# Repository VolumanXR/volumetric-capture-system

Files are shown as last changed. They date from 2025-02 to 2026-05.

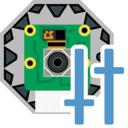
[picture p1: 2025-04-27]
src/res/master_camera_controller.png

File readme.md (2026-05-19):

**EN** | [DE](/README.de.md)

<p align="center">
  Volumetric Capture System Logo
</p>

# VolumanXR – Volumetric Capture System

This module is part of the **VolumanXR** project and implements a complete **synchronized volumetric video capture system** using Raspberry Pis and the Raspberry Pi Camera Module V3. The system enables real-time, multi-camera video acquisition for 4D Gaussian Splatting.
<p align="center">
  Animated results of a scan
</p>

It includes:
- A scalable and customizable camera rig
- A decentralized control system with synchronized recording
- GUI tools for capture, calibration, and download
- Automation scripts and config management

> **Maintenance Notice**\
>This repository primarily serves as a documentation and reference space for the Volumetric Capture System of the VolumanXR research project. Further development occurs on an occasional basis and is not continuous. Repositories may receive updates from time to time, but regular maintenance and long-term support should not be assumed.

---

## 📦 Repository Structure
```text
volumetric-capture-system/
├── readme.md
├── requirements.txt
├── cad/                           # 3D-printable camera holder models
├── src/
│   ├── master_camera_controller.py
│   ├── master_capture_controller.py
│   ├── master_download_manager.py
│   ├── config/                    # Device settings and camera parameters
│   ├── lib/                       # Shared configuration and SSH utilities
│   ├── remote/                    # Scripts executed on Raspberry Pis
│   ├── res/                       # Icons and sound files used by GUI tools
│   └── utils/                     # Utility scripts for setup and control
```

---

## 🔧 Hardware Context
<p align="center">
  Volumetric Capture System Overview Image
</p>

- **Camera Rig**: Custom-built frame using aluminum extrusion profiles (not included in repo).
- **Cameras**: Raspberry Pi 4B (1GB) + Camera Module V3
- **Devices**: approx. 70 Raspberry Pi units
- **Mounts**: 3D-printable camera holders (provided in `cad/`)
- **Trigger**: Software-synchronized using NTP + ZeroMQ

> *The structural skeleton is specific to our use case and therefore excluded to encourage custom modifications. It is based on standard 20×20mm aluminum extrusions, and the included 3D-printable camera holders are fully compatible with this profile size. A full parts list for the frame construction can be provided upon request.*

---

## 🚀 Core Functionality

### 🎚️ Master Camera Controller (`master_camera_controller.py`)
- GUI tool for live preview and global camera calibration
- Modify ISO, shutter speed, white balance, resolution
- Save unified settings to `camera_settings.json`

### 📸 Master Capture Controller (`master_capture_controller.py`)
- GUI-based tool to control still or video capture
- Synchronizes all agents to a single start time
- Frame drop detection and timestamp logging
- Uses `camera_list.json` to identify and manage all configured camera devices on the network

### 🔄 Master Download Manager (`master_download_manager.py`)
- GUI tool to download sessions from all Pis
- Organizes files, checks completeness, enables conversion
- Supports offline mode for post-capture frame extraction

---

## 🧠 Remote Agents (Running on Raspberry Pis)

Remote-side scripts are located in `src/remote/` and are triggered via SSH by the master control GUIs. Each script is responsible for a core function during capture, calibration, or data transfer.

### Main Remote Modules

- `remote_camera_controller.py`  
  Handles calibration commands from the Master Camera Controller (`master_camera_controller.py`), such as adjusting focus or setting exposure.

- `remote_capture_controller.py`  
  Receives synchronized recording instructions from the Master Capture Controller (`master_capture_controller.py`), executes the capture locally, and logs metadata.

- `remote_download_manager.py`  
  Runs a simple file server on each Pi to make captured sessions available for download, coordinated by the Master Download Manager (`master_download_manager.py`).

### Remote Utilities (`src/remote/utils/`)

- `remote_set_cam_number.py` — Sets a unique hostname, ID (e.g. `CAM00`) and fixed IP  
- `remote_test_camera_settings.py` — Applies a series of camera configurations and captures test images for validation

---

## 🧰 General Utilities

Located in `src/utils/`, these tools support discovery, setup, and remote control:

- `launcher.py`  
  CLI for development, debugging, and deployment. Supports multithreaded SSH to start/stop/update remote scripts on all Pis.

- `search_devices.py`  
  Scans the local subnet using multithreaded pings to identify active devices. Attempts to resolve hostnames for each responsive IP.

- `set_up_chrony_via_ssh.py`  
  Configures time synchronization on all Pis using Chrony for frame-accurate triggering.

- `master_set_cam_number.py`  
  Assigns camera numbers and hostnames from the master side during setup.

- `build.py`
  Preconfigured build script for all three main programs

---

## ⚙️ Configuration Files

- `camera_list.json` — List of camera hostnames, IPs, and their custom focus offsets
- `camera_settings.json` — Default global exposure settings (shutter, ISO, etc.)

Each Pi is matched via hostname (e.g. `CAM00`, `CAM01`, ...) and receives a fixed IP address in the `10.x.x.x` range.  
The **last octet of the IP corresponds to the camera number**, starting at `.100` — for example:
- `CAM00` → `10.x.x.100`
- `CAM01` → `10.x.x.101`

---
## 🗂 File Naming Convention

Captured videos and still images follow the pattern:
```
<session_name>_<ip_suffix>.<extension>
```

Examples:
- `DanceA_103.mp4` — video from device with IP `10.x.x.103`
- `PoseTest_115.jpg` — still image from device with IP `10.x.x.115`

This format ensures files can easily be traced to their originating capture device.

---

## 🎛 Dependencies

Install dependencies for local tools:

```bash
pip install -r requirements.txt
```
Recommended environment:
- Python 3.10+
- Works on Windows/macOS (for GUI tools) and Raspberry Pi OS (for remote agents)

---

## 👥 Contributions
### Code Contributors

- **Kai Altwicker** — Rig design, synchronization, master control architecture  
- **Dennis Amuser** — Remote agent design, firmware imaging, network & automation

### Publications
- **[IEEE VR26](https://doi.org/10.1109/VRW70859.2026.00274)**\
[Steffen Stein](https://www.linkedin.com/in/steffen-sascha-stein/), [Dennis Amuser](https://github.com/dooonnis), [Kai Altwicker](https://github.com/tallAldi), David Mertens, Matthias Bullert Alisa Rüge, David Martin Karf, Kristoffer Waldow, [Arnulph Fuhrmann](https://www.linkedin.com/in/arnulph-fuhrmann-291420279/)
```bibtex
@INPROCEEDINGS{11489551,
  author={Stein, Steffen-Sascha and Amuser, Dennis and Altwicker, Kai and Mertens, David and Bullert, Matthias and Ruge, Alisa and Karg, David Martin and Waldow, Kristoffer and Fuhrmann, Arnulph},
  booktitle={2026 IEEE Conference on Virtual Reality and 3D User Interfaces Abstracts and Workshops (VRW)}, 
  title={A Scalable and Cost-Effective Multi-View Capture System for Photorealistic Dynamic Human Reconstruction}, 
  year={2026},
  volume={},
  number={},
  pages={1199-1200},
  keywords={Broadcasting;Broadcast technology;Anisotropic;Filters;Graphical user interfaces;Avatars;Protocols;Videos;HTTP;Video equipment;Avatars;Capture System;Virtual Humans;Radiance Fields},
  doi={10.1109/VRW70859.2026.00274}}
```

### Acknowledgements
- Prof. Dr.-Ing. Fuhrmann
- GatewayTHK
- Makerspace TH Köln 
- Zentralwerkstatt Elektrotechnik, 

---

## 📄 License
 
Please refer to the [`LICENSE`](/LICENSE) file for full terms.

Third-party license notices are provided in [`THIRD_PARTY_NOTICES.md`](/NOTICE-THIRD-PARTY.md).

---

> ℹ️ This repository is part of the VolumanXR project. \
> For full project context, visit the [VolumanXR](https://github.com/VolumanXR) page.

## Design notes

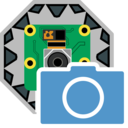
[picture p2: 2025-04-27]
src/res/master_capture_controller.png

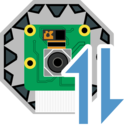
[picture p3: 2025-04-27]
src/res/master_download_manager.png

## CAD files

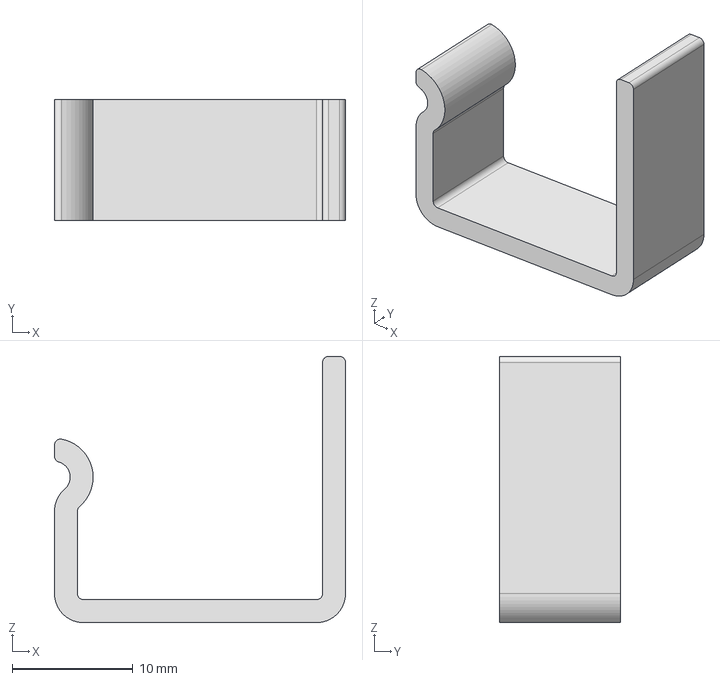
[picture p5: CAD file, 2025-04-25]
cad/Aruco_Marker_Clamp.stp
24.1 x 10.0 x 22.0 mm

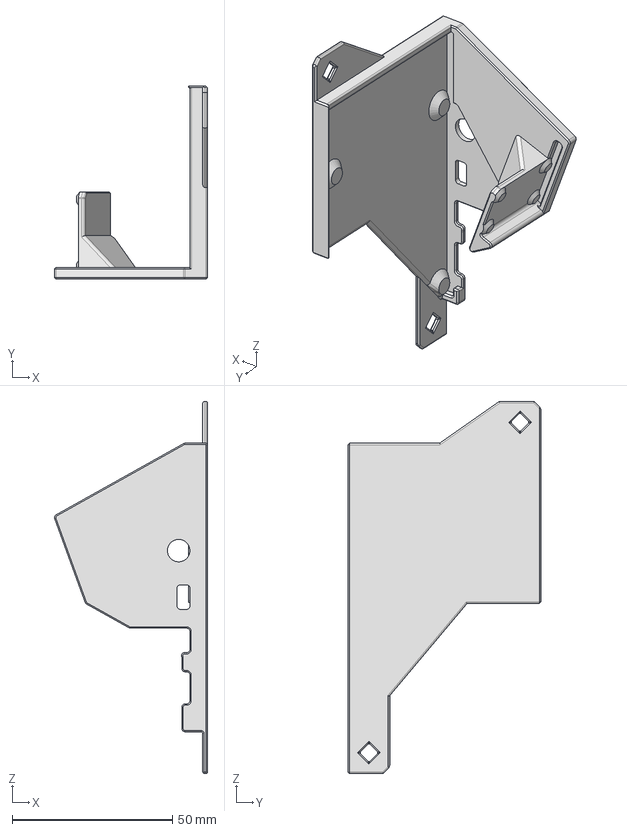
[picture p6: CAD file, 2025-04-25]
cad/Cameraholder_20deg_topDown.stp
47.7 x 60.1 x 116.0 mm

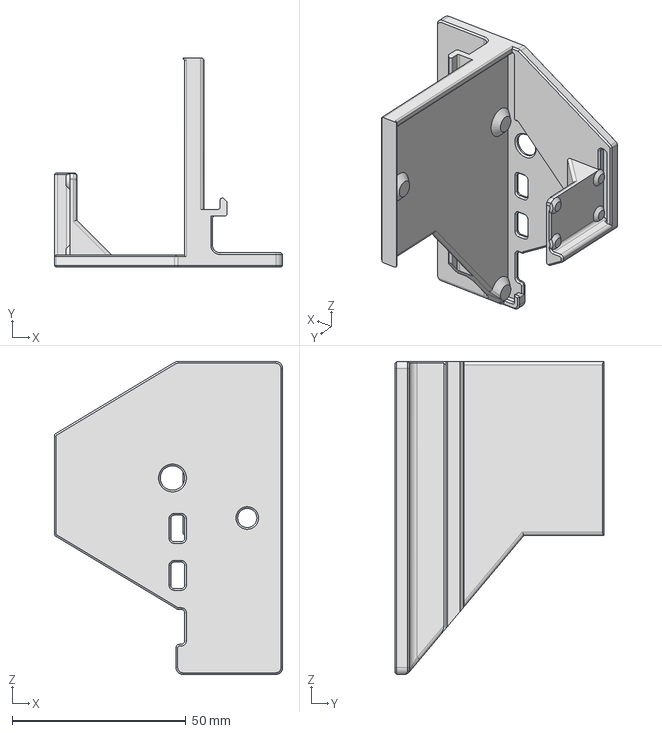
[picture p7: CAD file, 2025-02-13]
cad/Cameraholder_straight_90deg.stp
65.7 x 60.1 x 90.0 mm

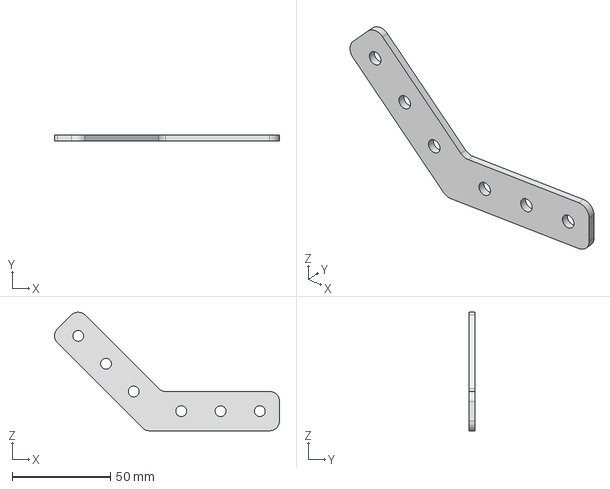
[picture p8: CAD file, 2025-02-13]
cad/Verbinder_45deg.stp
114.5 x 3.00 x 60.3 mm

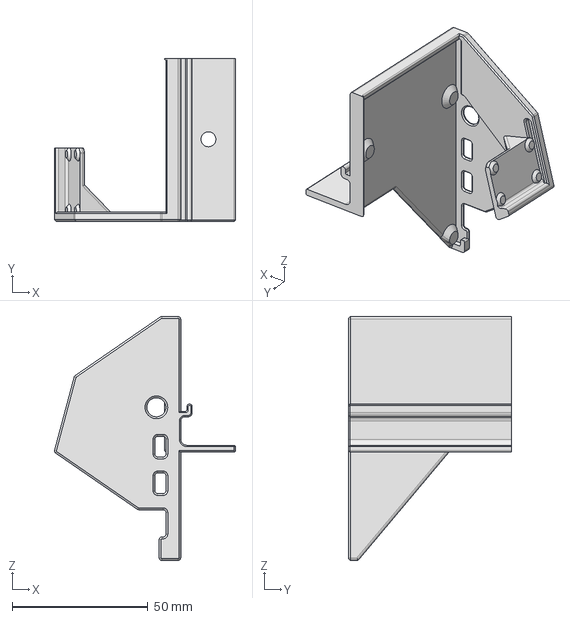
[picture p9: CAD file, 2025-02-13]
cad/Cameraholder_15deg_down.stp
66.8 x 60.1 x 90.0 mm

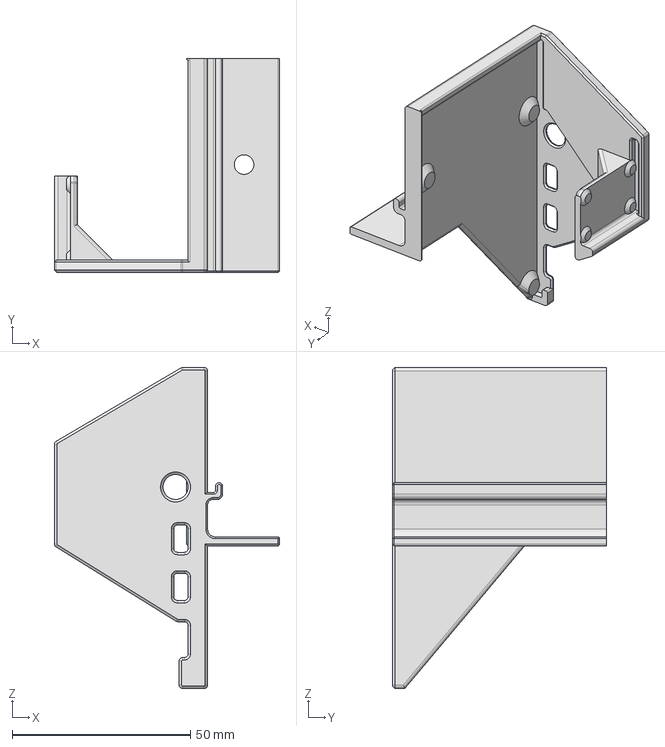
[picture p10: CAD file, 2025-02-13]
cad/Cameraholder_straight.stp
63.2 x 60.1 x 90.0 mm

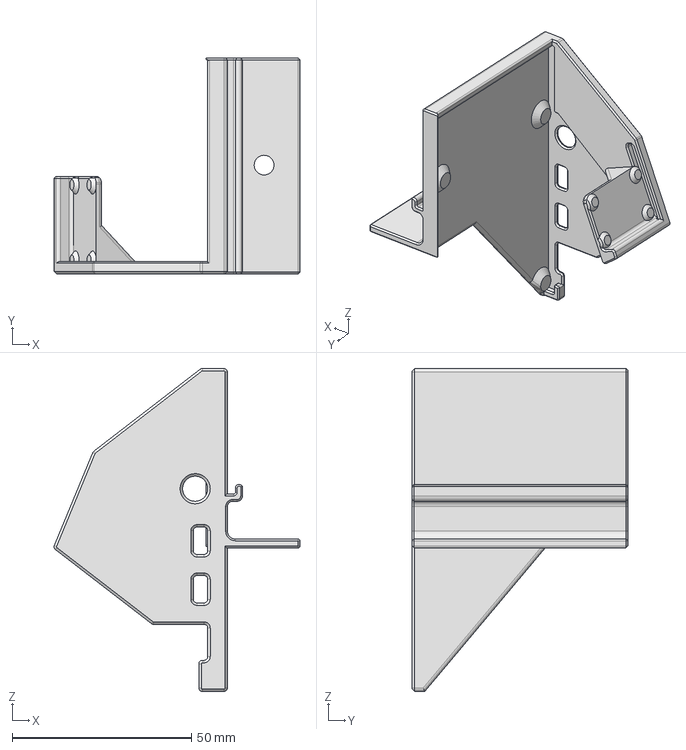
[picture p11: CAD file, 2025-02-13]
cad/Cameraholder_22_5deg_down.stp
68.5 x 60.1 x 90.0 mm

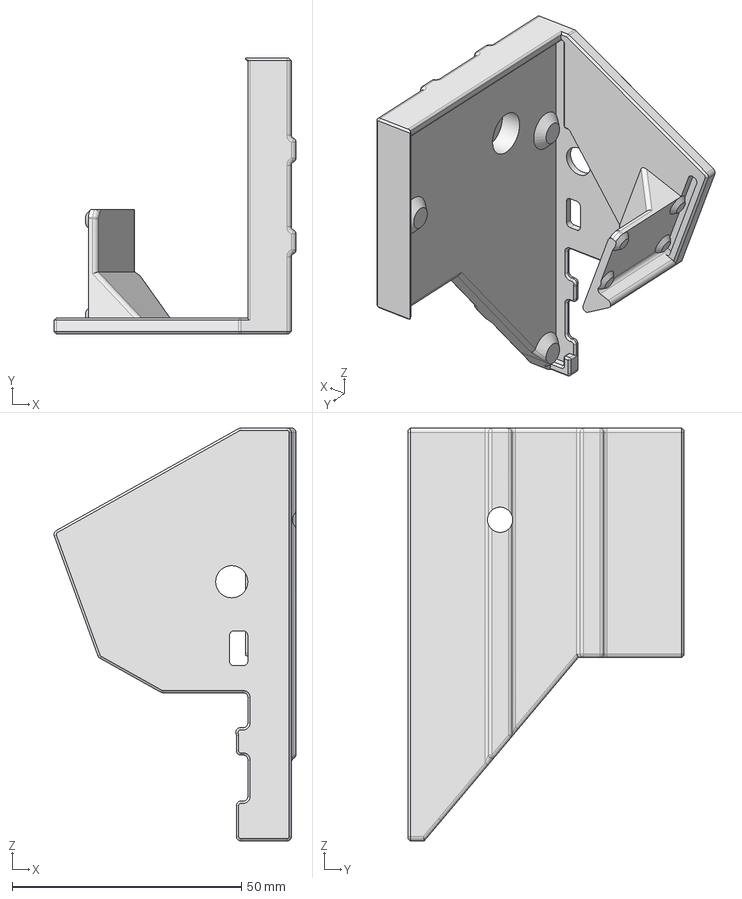
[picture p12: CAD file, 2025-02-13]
cad/Cameraholder_20deg_up.stp
52.7 x 60.1 x 90.0 mm

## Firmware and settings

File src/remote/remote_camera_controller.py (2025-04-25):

import os
import json
import logging
from flask import Flask, Response, request, jsonify
from picamera2 import Picamera2
import cv2
import time
import psutil 
import atexit
from libcamera import controls as libcontrols

logging.basicConfig(level=logging.DEBUG,
                    format='%(asctime)s %(levelname)s %(name)s: %(message)s',
                    datefmt='%Y-%m-%d %H:%M:%S')
logger = logging.getLogger(__name__)

app = Flask(__name__)

try:
    picam2 = Picamera2()
except Exception as e:
    logger.error(f"Failed to initialize Picamera2: {e}")
    exit(1)

def cleanup():
    try:
        picam2.stop()
        logger.info("Camera stopped and resources cleaned up.")
    except Exception as e:
        logger.error(f"Error during cleanup: {e}")

atexit.register(cleanup)

default_settings = {
    "width": 1920,
    "height": 1080,
    "frame_rate": 25,
    "shutter_angle": 20,
    "iso": 864,
    "brightness": 0,
    "contrast": 100,
    "saturation": 95,
    "sharpness": 129,
    "auto_exposure": False,
    "flicker_control": "Off",
    "flicker_period": 50,
    "white_balance": "Auto",
    "red_gain": 1.1,
    "blue_gain": 2.5,
    "af_mode": "manual",
    "lens_position": 0.58
}

if os.path.exists('camera_settings.json'):
    try:
        with open('camera_settings.json', 'r') as f:
            saved_settings = json.load(f)
            default_settings.update(saved_settings)
            logger.debug("Loaded settings from camera_settings.json")
    except Exception as e:
        logger.error(f"Failed to load camera_settings.json: {e}")

def apply_settings(settings):
    controls = {}
    frame_rate = float(settings.get('frame_rate', 25))
    controls["FrameRate"] = frame_rate

    shutter_angle = float(settings.get('shutter_angle', 180))
    base_exposure_time = (shutter_angle / 360.0) * (1.0 / frame_rate) * 1_000_000  # in microseconds

    iso_value = float(settings.get('iso', 100))

    controls["Brightness"] = float(settings.get('brightness', 0)) / 100.0
    controls["Contrast"] = float(settings.get('contrast', 100)) / 100.0
    controls["Saturation"] = float(settings.get('saturation', 100)) / 100.0
    controls["Sharpness"] = float(settings.get('sharpness', 100)) / 100.0

    flicker_selection = settings.get('flicker_control', 'Off')
    if flicker_selection == 'Off':
        controls["AeEnable"] = settings.get('auto_exposure', True)
        if not settings.get('auto_exposure', True):
            controls["ExposureTime"] = int(base_exposure_time)
            controls["AnalogueGain"] = iso_value / 100.0
    else:
        controls["AeEnable"] = False
        if flicker_selection == '50Hz':
            exposure_time = int(20_000)
        elif flicker_selection == '60Hz':
            exposure_time = int(16_667)
        elif flicker_selection == 'Manual':
# Use the flicker period from the settings
            flicker_period = float(settings.get('flicker_period', 50))  # in Hz
            exposure_time = int((1.0 / flicker_period) * 1_000_000)  # Convert Hz to microseconds
        else:
            exposure_time = int(base_exposure_time)

        controls["ExposureTime"] = exposure_time
        controls["AnalogueGain"] = iso_value / 100.0

    wb_selection = settings.get('white_balance', 'Auto')
    if wb_selection and wb_selection in ['Manual', '3200K', '4400K', '5600K']:
        controls["AwbEnable"] = False
        if wb_selection == 'Manual':
            red_gain = float(settings.get('red_gain', 1.0))
            blue_gain = float(settings.get('blue_gain', 1.0))
            controls["ColourGains"] = (red_gain, blue_gain)
        else:
            if wb_selection == '3200K':
                controls["ColourGains"] = (1.2, 2.3)
            elif wb_selection == '4400K':
                controls["ColourGains"] = (1.5,1.8)
            elif wb_selection == '5600K':
                controls["ColourGains"] = (1.8,1.5)
    else:
        controls["AwbEnable"] = True
        controls["AwbMode"]= getattr(libcontrols.AwbModeEnum, wb_selection, 0) # 0 = 'Auto'

    controls["AfMode"] = 2 if settings.get('af_mode', 'manual') == 'auto' else 0
    controls["LensPosition"] = settings.get('lens_position', 0.58)

    try:
        picam2.set_controls(controls)
        logger.debug(f"Applied settings: {controls}")
    except Exception as e:
        logger.error(f"Failed to apply settings: {e}")

def configure_camera():
    try:
        width = default_settings['width']
        height = default_settings['height']
        config = picam2.create_preview_configuration(
            main={"format": "RGB888", "size": (width, height)},
            controls={
                "FrameRate": float(default_settings['frame_rate']),
                "Brightness": float(default_settings['brightness']) / 100.0,
                "Contrast": float(default_settings['contrast']) / 100.0,
                "Saturation": float(default_settings['saturation']) / 100.0,
                "Sharpness": float(default_settings['sharpness']) / 100.0,
                "AwbEnable": default_settings['white_balance'] == 'Auto',
                "AeEnable": False if default_settings['flicker_control'] != 'Off' else default_settings['auto_exposure'],
            }
        )
        picam2.configure(config)
        picam2.start()
        apply_settings(default_settings)
        logger.debug("Camera configured and started.")
    except Exception as e:
        logger.error(f"Failed to configure and start camera: {e}")
        exit(1)

configure_camera()
logger.info("Camera successfully configured and started.")

@app.route('/controls', methods=['POST'])
def update_controls_route():
    try:
        settings = request.json
        if not settings:
            logger.warning("No settings provided in /controls POST request.")
            return jsonify({"error": "No settings provided"}), 400

        default_settings.update(settings)
        logger.debug(f"Received settings update: {settings}")

        apply_settings(default_settings)

        return jsonify({"status": "Settings updated successfully"}), 200
    except Exception as e:
        logger.error(f"Error in /controls endpoint: {e}")
        return jsonify({"error": str(e)}), 500

def generate_video_stream():
    while True:
        try:
            frame = picam2.capture_array()
            ret, buffer = cv2.imencode('.jpg', frame)
            if not ret:
                logger.warning("Failed to encode frame.")
                continue
            frame_bytes = buffer.tobytes()
            yield (b'--frame\r\n'
                   b'Content-Type: image/jpeg\r\n\r\n' + frame_bytes + b'\r\n')
            time.sleep(1 / default_settings['frame_rate'])
        except Exception as e:
            logger.error(f"Error generating video stream: {e}")
            break

@app.route('/video_feed')
def video_feed():
    return Response(generate_video_stream(),
                    mimetype='multipart/x-mixed-replace; boundary=frame')

@app.route('/save_settings', methods=['POST'])
def save_settings_route():
    try:
        settings = request.json
        if not settings:
            logger.warning("No settings provided in /save_settings POST request.")
            return jsonify({"error": "No settings provided"}), 400

        with open('camera_settings.json', 'w') as f:
            json.dump(settings, f)
        logger.debug("Settings saved to camera_settings.json")
        return jsonify({"status": "Settings saved successfully"}), 200
    except Exception as e:
        logger.error(f"Error in /save_settings endpoint: {e}")
        return jsonify({"error": str(e)}), 500

@app.route('/load_settings', methods=['GET'])
def load_settings_route():
    try:
        if os.path.exists('camera_settings.json'):
            with open('camera_settings.json', 'r') as f:
                saved_settings = json.load(f)
            logger.debug("Loaded settings from camera_settings.json")
            return jsonify(saved_settings), 200
        else:
            logger.debug("camera_settings.json not found. Returning default settings.")
            return jsonify(default_settings), 200
    except Exception as e:
        logger.error(f"Error in /load_settings endpoint: {e}")
        return jsonify({"error": str(e)}), 500

@app.route('/status', methods=['GET'])
def status_route():
    try:
        cpu_usage = psutil.cpu_percent(interval=1)
        return jsonify({"cpu_usage": cpu_usage}), 200
    except Exception as e:
        logger.error(f"Error in /status endpoint: {e}")
        return jsonify({"error": str(e)}), 500

if __name__ == '__main__':
    logger.info("Starting Flask server...")
    try:
        app.run(host='0.0.0.0', port=5000, threaded=True, debug=False, use_reloader=False)
    except Exception as e:
        logger.error(f"Failed to start Flask server: {e}")
        picam2.stop()
        logger.info("Shutting down camera due to Flask server failure.")

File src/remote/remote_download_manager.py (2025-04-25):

#!/usr/bin/env python3
# remote_download_manager.py v12

import socket
import threading
import os
import json
import struct
import zmq

# Configuration
UDP_IP = "0.0.0.0"       # Listen on all interfaces for UDP
UDP_PORT = 50006
TCP_PORT = 50007        
RECORDINGS_FOLDER = "Recordings"  

# Supported file extensions for a session.
SUPPORTED_EXTENSIONS = ('.h264', '.jpg', '.mp4', '.json')

def get_suffix():
    s = socket.socket(socket.AF_INET, socket.SOCK_DGRAM)
    try:
        s.connect(('8.8.8.8', 1))
        IP = s.getsockname()[0]
    except Exception:
        IP = '127.0.0.1'
    finally:
        s.close()
    suffix = '_' + IP.split('.')[-1]
    return suffix

SUFFIX = get_suffix()
print(f"Raspberry Pi suffix: {SUFFIX}")

def get_session_names():
    if not os.path.exists(RECORDINGS_FOLDER):
        return []
    files = os.listdir(RECORDINGS_FOLDER)
    sessions = set()
    for file in files:
        if file.lower().endswith(SUPPORTED_EXTENSIONS):
            base_name, ext = os.path.splitext(file)
            if '_' in base_name:
                session_name = '_'.join(base_name.split('_')[:-1])
            else:
                session_name = base_name
            sessions.add(session_name)
    return list(sessions)

def get_session_files(session_name):
    found_paths = []
    if not os.path.exists(RECORDINGS_FOLDER):
        return found_paths

    for file in os.listdir(RECORDINGS_FOLDER):
        if file.lower().endswith(SUPPORTED_EXTENSIONS):
            base_name, ext = os.path.splitext(file)
            if '_' in base_name:
                prefix = '_'.join(base_name.split('_')[:-1])
                if prefix == session_name and base_name.endswith(SUFFIX):
                    full_path = os.path.join(RECORDINGS_FOLDER, file)
                    found_paths.append(full_path)
    return found_paths

def handle_udp_request(data, addr, sock):
    try:
        request = json.loads(data.decode())
    except json.JSONDecodeError:
        return

    action = request.get('action')
    if action == "GET_SESSIONS":
        sessions = get_session_names()
        response = {"sessions": sessions}
        sock.sendto(
            json.dumps(response).encode(), addr
        )
        print(f"Sent session list to {addr}")

    elif action == "GET_SESSION_INFO":
        session_name = request.get('session_name')
        files = get_session_files(session_name)
        if files:
            total_size = sum(
                os.path.getsize(fp) for fp in files
            )
            response = {"status": "OK", "file_size": total_size}
        else:
            response = {"status": "NOT_FOUND"}
        sock.sendto(
            json.dumps(response).encode(), addr
        )

    elif action == "DELETE_SESSION":
        session_name = request.get('session_name')
        files = get_session_files(session_name)
        if not files:
            response = {
                "status": "ERROR", 
                "message": "File not found"
            }
            sock.sendto(
                json.dumps(response).encode(), addr
            )
            print(f"No files found for session '{session_name}' from {addr}")
        else:
            success = True
            errors = []
            for fp in files:
                try:
                    os.remove(fp)
                except Exception as e:
                    success = False
                    errors.append(str(e))
            if success:
                response = {"status": "OK"}
                print(f"Deleted session '{session_name}' for {addr}")
            else:
                msg = (
                    "Failed to delete some files: " + "; ".join(errors)
                )
                response = {
                    "status": "ERROR", 
                    "message": msg
                }
                print(msg)
            sock.sendto(
                json.dumps(response).encode(), addr
            )

    elif action == "DELETE_ALL_SESSIONS":
        files = []
        for session in get_session_names():
            files.extend(get_session_files(session))
        if not files:
            response = {
                "status": "ERROR", 
                "message": "No files found"
            }
            sock.sendto(
                json.dumps(response).encode(), addr
            )
            print(f"No files found to delete from {addr}")
        else:
            success = True
            errors = []
            for fp in files:
                try:
                    os.remove(fp)
                except Exception as e:
                    success = False
                    errors.append(str(e))
            if success:
                response = {"status": "OK"}
                print(f"Deleted all sessions for {addr}")
            else:
                msg = (
                    "Failed to delete some files: " + "; ".join(errors)
                )
                response = {
                    "status": "ERROR", 
                    "message": msg
                }
                print(msg)
            sock.sendto(
                json.dumps(response).encode(), addr
            )

    else:
        print(f"Received unknown UDP action: {action} from {addr}")

def udp_server():
    sock = socket.socket(socket.AF_INET, socket.SOCK_DGRAM)
    sock.bind((UDP_IP, UDP_PORT))
    print("UDP server is up and listening on port", UDP_PORT)
    while True:
        data, addr = sock.recvfrom(4096)
        handle_udp_request(data, addr, sock)
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

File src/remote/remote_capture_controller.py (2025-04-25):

# remote_capture_controller.py v11

import os
import time
import json
import hashlib
import subprocess
import threading
import zmq
import uuid
import sys
import signal
import datetime

from picamera2 import Picamera2, Preview
from picamera2.encoders import H264Encoder
from picamera2.outputs import FileOutput
from libcamera import controls as libcontrols

EVENT_LOG = 'event_log.txt'
STORAGE_PATH = 'Recordings'
CAMERA_SETTINGS_FILE = 'camera_settings.json'

def get_master_ip_address():
    if len(sys.argv) > 1:
        return sys.argv[1]
    return '10.50.100.2'

def get_custom_lens_position():
    if len(sys.argv) > 2:
        return sys.argv[2]
    return None

MASTER_PC_IP = get_master_ip_address()
CUSTOM_LENS_POSITION = get_custom_lens_position()

def get_ip_address():
    import netifaces
    interfaces = netifaces.interfaces()
    for interface in interfaces:
        if interface == 'lo':
            continue
        addresses = netifaces.ifaddresses(interface)
        if netifaces.AF_INET in addresses:
            for addr_info in addresses[netifaces.AF_INET]:
                return addr_info['addr']
    return 'Unknown'

my_ip = get_ip_address()

MASTER_PC_PORT = 50005

STANDBY = 'STANDBY'
PREPARING = 'PREPARING'
RECORDING = 'RECORDING'
PREPARING_STILL = 'PREPARING_STILL'

state = STANDBY
session_name = ''
recording_file = ''
timecode = '00:00:00:00'
fps = 25

if not os.path.exists(STORAGE_PATH):
    os.makedirs(STORAGE_PATH)

default_settings = {
    "width": 1920,
    "height": 1080,
    "frame_rate": 25,
    "shutter_angle": 20,
    "iso": 560,
    "brightness": 0,
    "contrast": 100,
    "saturation": 95,
    "sharpness": 129,
    "auto_exposure": False,
    "flicker_control": "Off",
    "flicker_period": 50,
    "white_balance": "Daylight",
    "red_gain": 1.1,
    "blue_gain": 2.5,
    "af_mode": "manual",
    "lens_position": 0.36
}
if os.path.exists(CAMERA_SETTINGS_FILE):
    with open(CAMERA_SETTINGS_FILE, 'r') as f:
        saved_settings = json.load(f)
        default_settings.update(saved_settings)

def log_event(message):
    timestamp = time.strftime('%Y-%m-%d %H:%M:%S')
    with open(EVENT_LOG, 'a') as log_file:
        log_file.write(f'[{timestamp}] {message}\n')

picam2 = Picamera2()
encoder = None

def apply_settings(settings):
    controls = {}
    frame_rate = float(settings.get('frame_rate', 25))
    controls["FrameRate"] = frame_rate
    shutter_angle = float(settings.get('shutter_angle', 180))

    width, _ = picam2.stream_configuration("main")["size"]
    if width > 1920:
        shutter_angle = shutter_angle * 2

    base_exposure_time = (
        (shutter_angle / 360.0) * (1.0 / frame_rate) * 1_000_000
    )
    iso_value = float(settings.get('iso', 100))

    controls["Brightness"] = float(settings.get('brightness', 0)) / 100.0
    controls["Contrast"] = float(settings.get('contrast', 100)) / 100.0
    controls["Saturation"] = float(settings.get('saturation', 100)) / 100.0
    controls["Sharpness"] = float(settings.get('sharpness', 100)) / 100.0

    flicker_selection = settings.get('flicker_control', 'Off')
    if flicker_selection == 'Off':
        controls["AeEnable"] = settings.get('auto_exposure', True)
        if not settings.get('auto_exposure', True):
            controls["ExposureTime"] = int(base_exposure_time)
            controls["AnalogueGain"] = iso_value / 100.0
    else:
        controls["AeEnable"] = False
        if flicker_selection == '50Hz':
            exposure_time = int(20000)
        elif flicker_selection == '60Hz':
            exposure_time = int(16667)
        elif flicker_selection == 'Manual':
            flicker_period = float(settings.get('flicker_period', 50))
            exposure_time = int((1.0 / flicker_period) * 1_000_000)
        else:
            exposure_time = int(base_exposure_time)
        controls["ExposureTime"] = exposure_time
        controls["AnalogueGain"] = iso_value / 100.0

    wb_selection = settings.get('white_balance', 'Auto')
    if wb_selection and wb_selection in ['Manual', '3200K', '4400K', '5600K']:
        controls["AwbEnable"] = False
        if wb_selection == 'Manual':
            red_gain = float(settings.get('red_gain', 1.0))
            blue_gain = float(settings.get('blue_gain', 1.0))
            controls["ColourGains"] = (red_gain, blue_gain)
        else:
            if wb_selection == '3200K':
                controls["ColourGains"] = (1.2, 2.3)
            elif wb_selection == '4400K':
                controls["ColourGains"] = (1.5, 1.8)
            elif wb_selection == '5600K':
                controls["ColourGains"] = (1.8, 1.5)
    else:
        controls["AwbEnable"] = True
        controls["AwbMode"] = getattr(libcontrols.AwbModeEnum, wb_selection, 0) # 0 == Auto WhiteBalance

    if settings.get('af_mode', 'manual') == 'auto':
        controls["AfMode"] = 2
    else:
        controls["AfMode"] = 0

    if CUSTOM_LENS_POSITION is not None:
        controls["LensPosition"] = float(CUSTOM_LENS_POSITION)
        log_event(f"Using custom lens position: {controls['LensPosition']}")
    else:
        controls["LensPosition"] = settings.get('lens_position', 0.36)
        log_event(f"Using default lens position: {controls['LensPosition']}")

    try:
        picam2.set_controls(controls)
    except Exception as e:
        log_event(f"Error applying settings: {e}")

def configure_camera(custom_resolution=None):
    if custom_resolution is not None:
        if custom_resolution == 'FullHD':
            width = 1920
            height = 1080
        elif custom_resolution == 'HD':
            width = 1280
            height = 720
        elif custom_resolution == 'SD':
            width = 640
            height = 480
        elif custom_resolution == 'UHD':
            width = 3840
            height = 2160
        else:
            width = default_settings['width']
            height = default_settings['height']
    else:
        width = default_settings['width']
        height = default_settings['height']

    video_config = picam2.create_video_configuration(
        main={"size": (width, height)}
    )
    picam2.configure(video_config)
    picam2.start()
    picam2.options["quality"] = 100
    apply_settings(default_settings)

configure_camera()
log_event("Camera configured and started.")

def get_storage_remaining():
    statvfs = os.statvfs(STORAGE_PATH)
    remaining = (statvfs.f_frsize * statvfs.f_bavail) / (1024 * 1024)
    return int(remaining)
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

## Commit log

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2024-09-27 Added dimension sheet
    [dimensions.xlsx]
2024-10-07 Mockup for aluminium profiles instead of tubes
    [Mockup_v3.ipt]
2024-10-13 Added Mockup
    [Mockup_v3.ipt]
2024-10-13 Added standard templates and modified dimensions sheet
    [Standard.iam, Standard.ipt, dimensions.xlsx]
2024-10-13 finished cad construction of alu profiles for rig
    [Profil_5_20x20_1500.ipt, Profil_5_20x20_2000.ipt, Profil_5_20x20_460.ipt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]
2024-10-13 Added dummy and floor for renderings
    [Boden.ipt, Segment_Staender_v1.iam]
2024-10-14 Added partlist
    [Partlist.xlsx]
2024-10-14 Added Material for Weight measurement
    [Boden.ipt, Profil_5_20x20_1500.ipt]
2024-10-14 Added 45deg connector
    [Standard.dwg, Verbinder_45deg.dxf, Verbinder_45deg.ipt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]
2024-10-14 Added dimension to dxf
    [Verbinder_45deg.dxf]
2024-10-17 Updated with foot design
    [Segment_Staender_v1.iam]
2024-10-17 Reworked rig into rig_v2
    Connections betweens aluminium profiles is now realised with lasercut 45deg connectors
    [Boden.ipt, Profil_5_20x20_1500.ipt, Profil_5_20x20_2000.ipt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]
2024-10-17 Added rig_v2.1
    rig_v2.1 contains possibilities to enlarge the rig in the future by providing a option for a hexadecagon(16 sides)
    [Profil_5_20x20_1500.ipt, Profil_5_20x20_2000.ipt, Profil_5_20x20_460.ipt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]
2024-10-18 Added prototype for camera firmware (UNTESTED)
    Prototype provides a framework with statemachine for different camera stages (STANDBY, RECORDING, READY_FOR_TRANSMIT) and also handles recieving and sending corresponding UDP messages
    libcamera is used as a subprocess to controll the camera
2024-10-18 Updated partslist rig_v1 + added partslists rig_v2, rig_v2.1
    [Partlist.xlsx, Partlist_v2.xlsx, Partlist_v2_1.xlsx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]
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2024-10-28 Added camera holder (WIP)
    [Camera_Assembly.iam, Rig_v2.iam, VolumanXR_Rig_Cameraholder_v01.ipt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]
2024-10-28 Added camera holder V3
    camera holder is now functional for holding the pi and camera module
    camera module is aligned straight (orthogonal to mounting profile)
    [Rig_v2.iam, VolumanXR_Rig_Cameraholder_v03.ipt, VolumanXR_Rig_Cameraholder_v03.stp]
2024-11-07 Added electrical parts
    [Stromversorgung.iam]
2024-11-07 Revised Cameraholder of top row
    Adjusted according to the vertical viewing angle to angle the cameras downwards for better coverage
    [dimensions.xlsx]
2024-11-07 Finished CAD model
    CAD construction is finished for the time beeing
    Electrical components are added and wire length can be calculated from the parts list
    Top camera holders have been added to provide better coverage
    For all other rows camera holders are simply perpenticular to the holding rod, without being aligned to the rig's center. According to findings from TRAINING-team alignment has only negligible influe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
    [Camera_Assembly_Electrical.ipt, Kabel.iam, Partlist_v2.xlsx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]
2024-11-08 Added top row camera holder
    [VolumanXR_Rig_Cameraholder_v04.stp]
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2024-11-12 updated partslist for first delivery of material
    [Partlist_v2.xlsx]
2024-11-13 Added bottom camera holder
    [VolumanXR_Rig_Cameraholder_v05.ipt, VolumanXR_Rig_Cameraholder_v05.stp]
2024-11-13 Added utils folder + script to find optimzed lens position for given focus distance
    The script assumes that a siemens star is used as target
2024-11-13 Added bottom camera holder to rig model
    [Rig_v2.Kabelbaum1.iam, Rig_v2.Kabelbaum1.ipt, Schablone_45deg_Verbinder.ipt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]
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2024-11-25 added lasecut panel for 45deg connectors
    [Verbinder_45deg_Panel.dxf]
2024-11-26 Added distance gauge to help with construction
    [Abstandslehre#.iam, Fuß.ipt, Kopf.ipt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]
2024-12-03 Tools for rig construction
    [Stab.dxf, Stab.ipt, Verbinder_45deg_Panel.dxf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]
2024-12-03 visualization of interpretationvolume
    [Interpolationsvolumen.dxf, Rig_v2_Interpolationsvolumen.ipt]
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2024-12-11 Added csv for ip adresses and hostnames
    [ip_config.csv]
2024-12-16 testing on multiple pis
    [pi_config.txt]
2024-12-18 tried new sync method but failed
    [pi_config.txt]
2024-12-19 updated ip list
    [ip_config.csv]
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2024-12-21 Moved utils folder
    [ip_config.csv]
2024-12-21 Adjusted IP addresses to new network
    [pi_config.txt]
2025-01-09 added version number + reworked paths for camera_list.json
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2025-01-14 Adjusted camera settings to prevent motion blur
2025-01-19 Added reworked bottom cameraholder
    [VolumanXR_Rig_Cameraholder_v06.ipt, VolumanXR_Rig_Cameraholder_v06.stp]
2025-01-19 Updated top camera holder
    [VolumanXR_Rig_Cameraholder_v07.ipt, VolumanXR_Rig_Cameraholder_v07.stp]
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2025-02-04 updated camerasettings + fixed 4K photo
    adjusted for new lighting situation
    modified white balance routine
    set wb to dayligt to match lights
    half the shutterspeed when 4k is detected to compensate exposure
2025-02-06 (working) on framedrops - broken!
2025-02-07 BUGFIX: Remove cam from connected cameras at no response
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2025-02-10 First release (WIP)
    [Mockup_v3.ipt, Standard.iam, Standard.ipt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]
2025-02-13 Tidy up
    [Abstandslehre.iam, Boden.ipt, Camera_Assembly_Electrical.ipt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]
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2025-02-18 reworked white balance to accept libcamera enums + manuell mode from camera controller
    [remote_camera_controller.py]
2025-02-18 TESTED: Presets work correctly + Color temperatur colourGains adjusted to mirror pi Color transform curve
    [remote_camera_controller.py]
2025-02-27 UPDATED: Filepath for library assets
    [Segment_Staender_v1.iam, Verbinder_45deg_Satz.iam, VolumanXR_Rig_Cameraholder_v01.ipt]
2025-02-28 BUGFIX: working script to set up new cameras
    [remote_set_cam_number.py]
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2025-04-15 fixed autostart in camera controller
2025-04-15 FEATURE FREEZE
    Feature development has finished
    No new features will be added
    After this commit only code review, bugfixes and tidy ups are allowed
    [remote_set_cam_number.py, remote_test_camera_settings.py]
2025-04-15 TidyUp + adjusted filepaths
    First step to reorganize structure for release
    Not needed versions deleted
    Creation of /lib, /res and /config folders + adjusted filepaths in scripts
    [Mockup_v3.ipt, Standard.iam, Standard.ipt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]
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2025-04-20 Added 4 top cameras
    Focus not possible due to the focus element affect by gravity. VCM is too weak to move against gravity
2025-04-20 ADDED: top camera holder + aruco clamps
    [Aruco_Marker_Clamp.ipt, Aruco_Marker_Clamp.stp, Aruco_Marker_Clamp_2.stp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]
2025-04-20 ADDED: Graphic files for documentation
    [Interpolationsvolumen.dxf, Interpolationsvolumen_Vertikal.dxf, Interpolationsvolumen_mit_Oktagon.dxf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]
2025-04-25 TidyUp to prepare for merge
    [Abstandslehre.iam, Aruco_Marker_Clamp.ipt, Aruco_Marker_Clamp.stp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]
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
